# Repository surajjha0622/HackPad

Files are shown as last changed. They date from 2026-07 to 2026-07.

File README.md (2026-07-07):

# HackPad

A compact 6-key programmable macropad built using the **Seeed Studio XIAO RP2040**.

HackPad started as a project to learn the complete hardware design workflow—from schematic capture and PCB design to enclosure design and firmware development. Instead of using an existing macropad, I wanted to build one from scratch and understand every part of the process.

The project combines mechanical switches, a rotary encoder, and a small OLED display into a compact device that can be customized for productivity, media control, programming shortcuts, CAD software, or everyday workflows.

---

## Features

- 6 Mechanical Keys
- Rotary Encoder with Push Button
- 0.91" SSD1306 OLED Display
- USB Type-C Connectivity
- Powered by Seeed Studio XIAO RP2040
- Custom PCB designed in KiCad
- 3D Printed Enclosure
- QMK Firmware 

---

## PCB

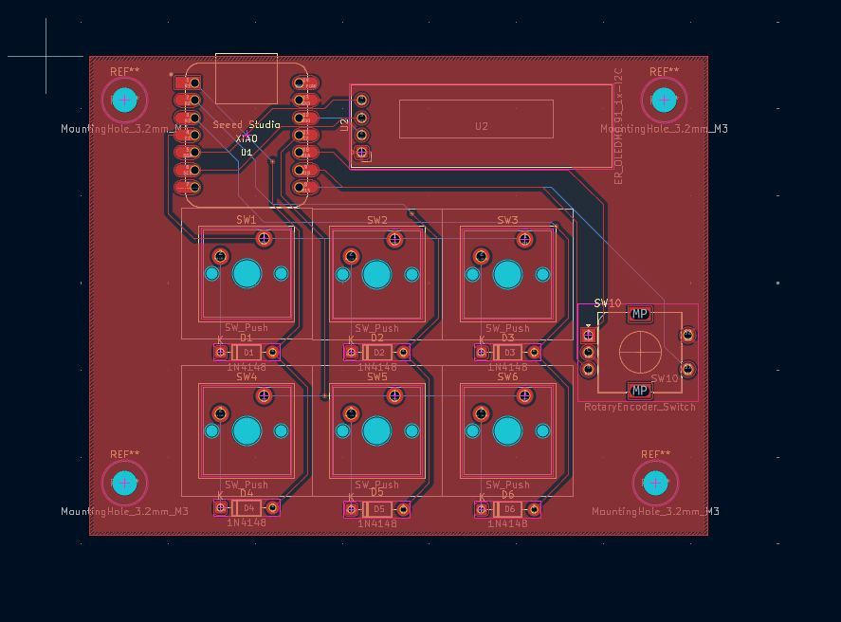
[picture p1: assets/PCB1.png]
PCB


---

## Schematic

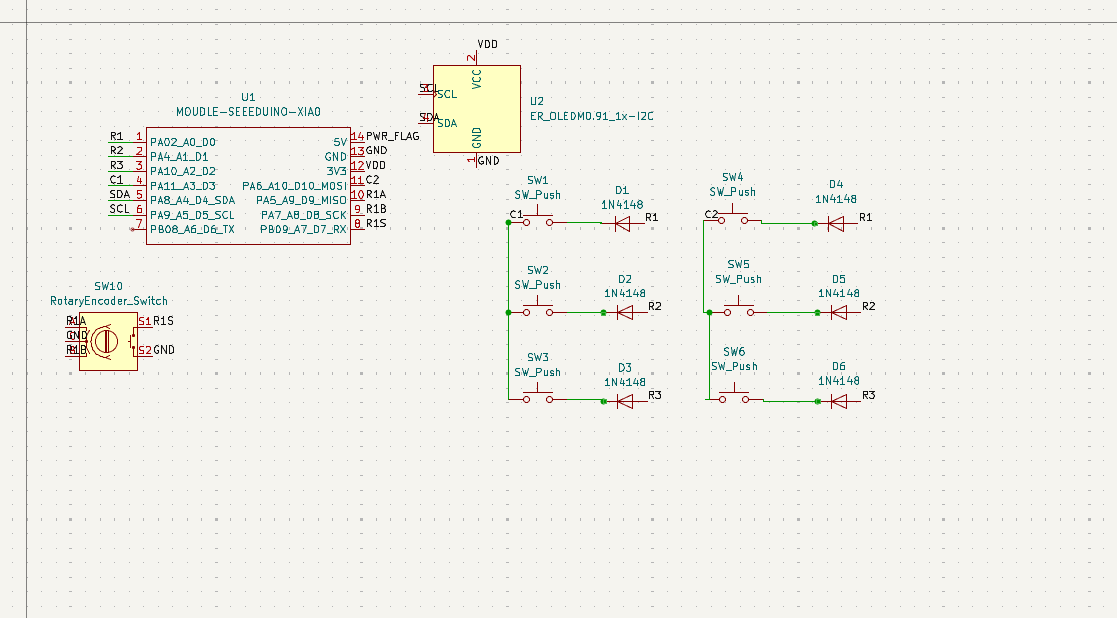
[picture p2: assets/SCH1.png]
SCHEMATICS


---

## 3D PCB Render

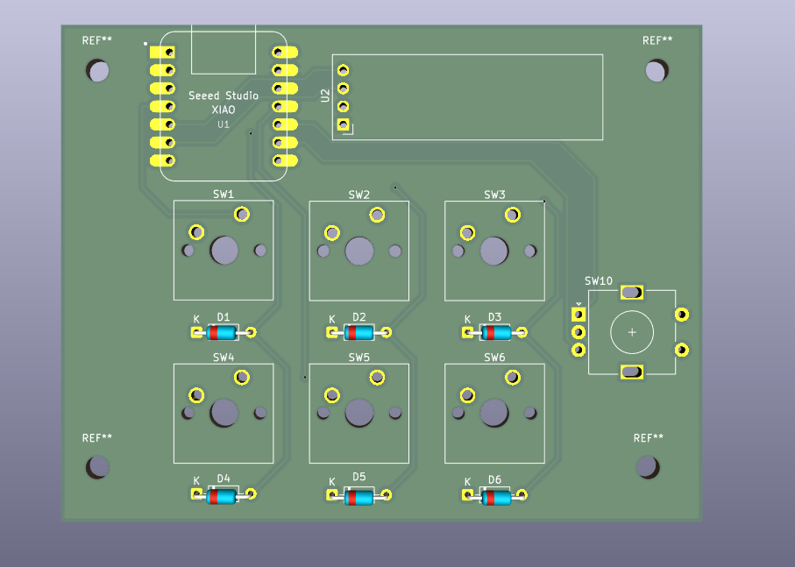
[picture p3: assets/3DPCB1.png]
3D PCB


---

## Enclosure Design

| Front | Edge |
|:---:|:----:|
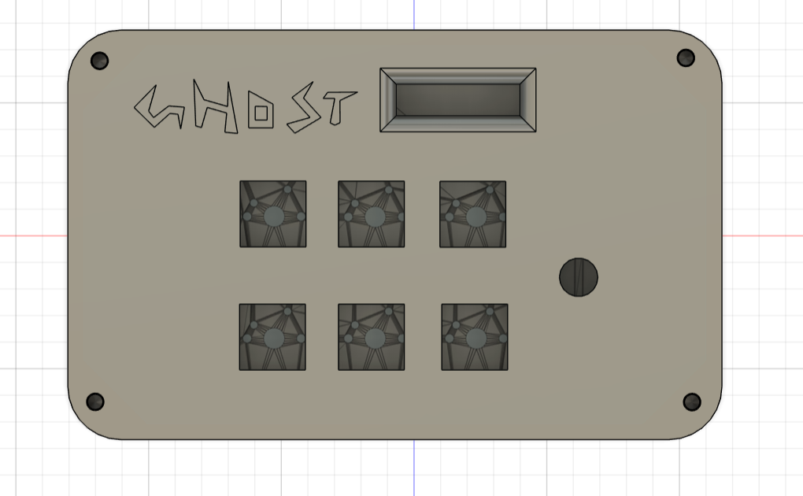
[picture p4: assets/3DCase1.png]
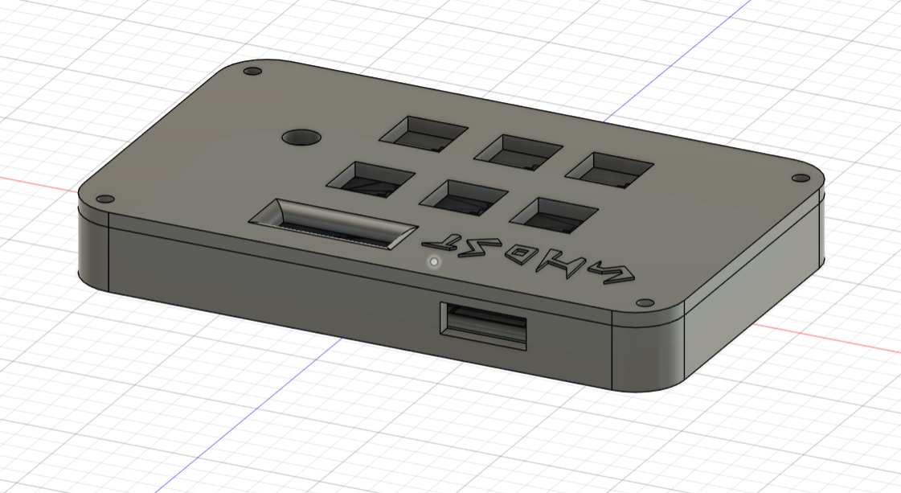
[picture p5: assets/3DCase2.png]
|  |  |

<p align="center">
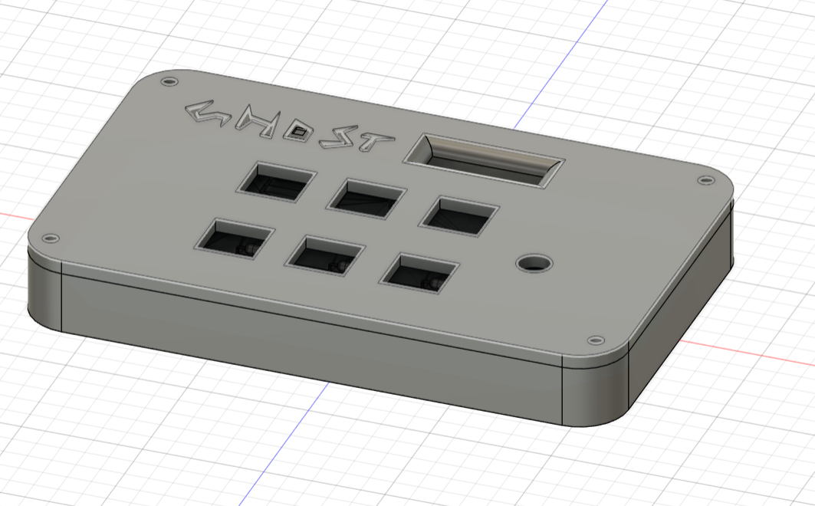
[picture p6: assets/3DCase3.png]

</p>

---

## Tech Stack

- KiCad 9
- Seeed Studio XIAO RP2040
- QMK Firmware *(In Progress)*
- 3D Printing
- Git & GitHub

---

## Current Status

- ✅ Schematic Complete
- ✅ PCB Designed
- ✅ 3D PCB Verified
- ✅ Enclosure Designed
- ✅ Gerber Files Generated
- 🔄 Firmware Development
- ⏳ PCB Manufacturing
- ⏳ Assembly & Testing

---

## What I Learned

This project helped me gain hands-on experience with:

- PCB Design
- Schematic Design
- Component Selection
- PCB Routing
- 3D Enclosure Design
- Hardware Documentation
- GitHub Project Organization

---

## 🤝 Feedback

This project is still evolving, and I'd love to hear suggestions or ideas for improvements. If you spot something that could be done better, feel free to open an issue or reach out!

Thanks for checking out HackPad! 🚀

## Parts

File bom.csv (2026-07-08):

Item | Quantity | Estimated Cost (USD)
Seeed Studio XIAO RP2040 | 1 | Included in Kit
MX-Style Mechanical Switches | 6 | Included in Kit
White DSA Keycaps | 6 | Included in Kit
1N4148 Through-Hole Diodes | 6 | Included in Kit
EC11 Rotary Encoder | 1 | Included in Kit
0.91" SSD1306 OLED Display | 1 | Included in Kit
Custom PCB | 1 | $10.00
3D Printed Enclosure | 1 | $10.00
M3 Heatset Inserts | 6 | Included in Kit
M3×16mm Screws | 6 | Included in Kit
Solder Wire | 1 | $2.00
Flux | 1 | $3.00
Soldering Iron | 1 | $15.00

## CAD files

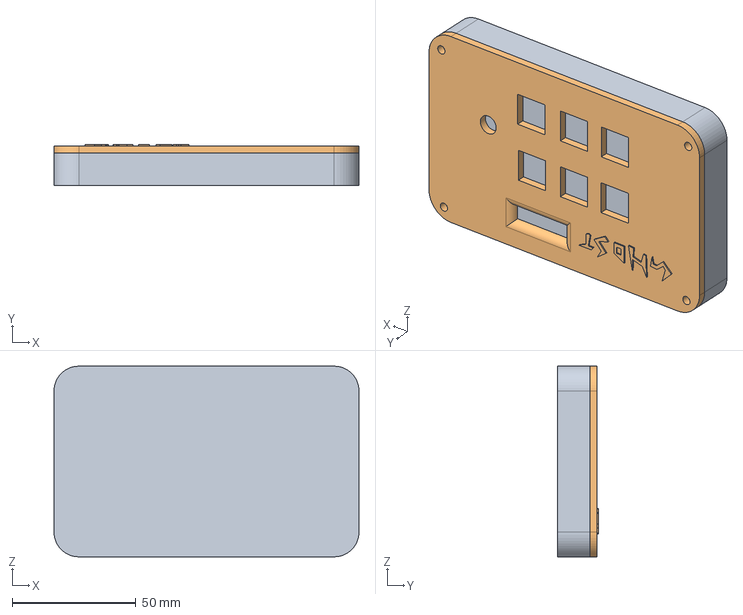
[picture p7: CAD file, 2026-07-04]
hardware/CAD/HackPad_Case_v1.step
123.2 x 16.5 x 77.0 mm

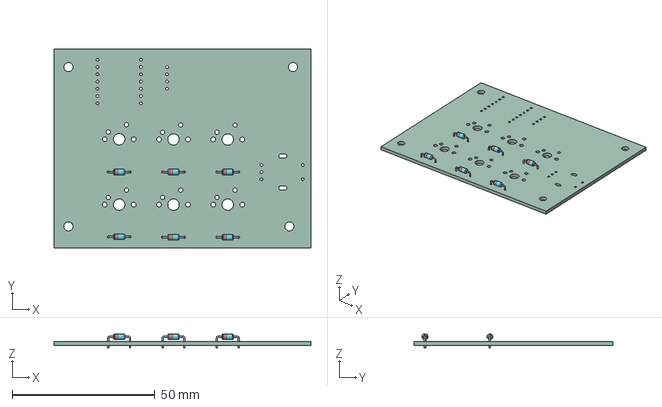
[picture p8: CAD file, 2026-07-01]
hardware/CAD/.step
90.2 x 69.9 x 5.01 mm
D_DO-35_SOD27_P7.62mm_Horizontal x 6
MicroPad_PCB

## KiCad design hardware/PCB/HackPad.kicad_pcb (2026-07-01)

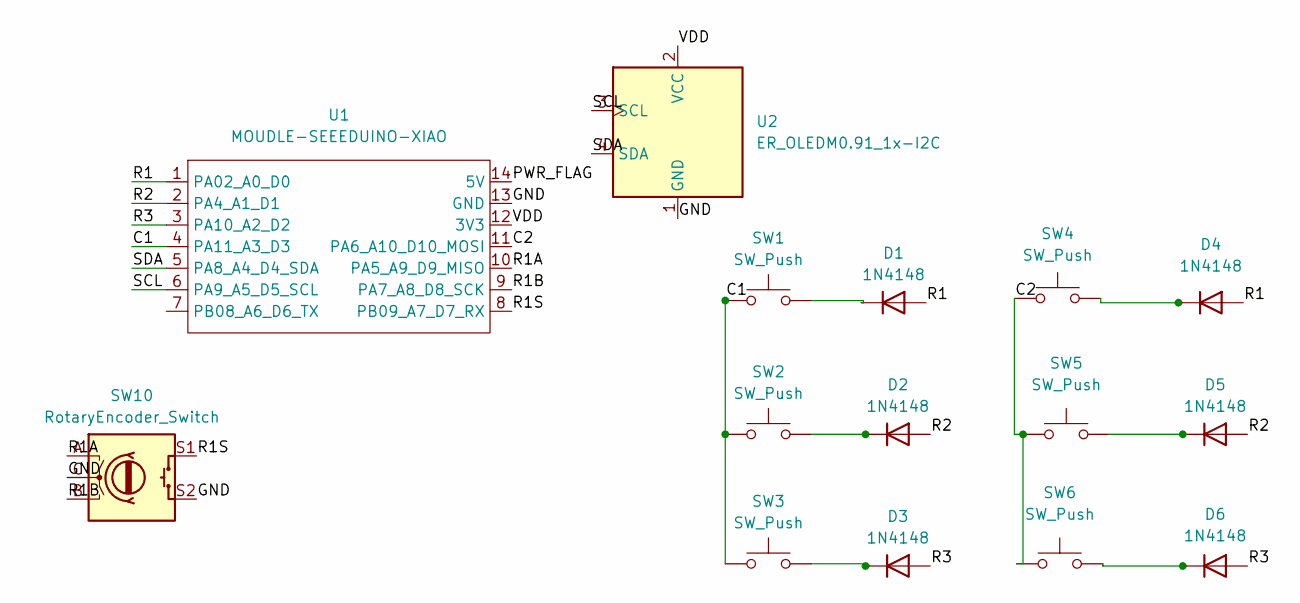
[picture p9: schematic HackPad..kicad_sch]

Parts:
D1, D2, D3, D4, D5, D6: 1N4148; D_DO-35_SOD27_P7.62mm_Horizontal
SW1, SW2, SW3, SW4, SW5, SW6: SW_Push; SW_Cherry_MX_1.00u_PCB
SW10: RotaryEncoder_Switch; RotaryEncoder_Alps_EC11E-Switch_Vertical_H20mm
U1: MOUDLE-SEEEDUINO-XIAO; XIAO-Generic-Hybrid-14P-2.54-21X17.8MM
U2: ER_OLEDM0.91_1x-I2C

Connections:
/C1: SW1.1, SW2.1, SW3.1, U1.4 (PA11_A3_D3)
/C2: SW4.1, SW5.1, SW6.1, U1.11 (PA6_A10_D10_MOSI)
/GND: SW10.C, SW10.S2, U1.13 (GND), U2.1 (GND)
/PWR_FLAG: U1.14 (5V)
/R1: D1.2 (A), D4.2 (A), U1.1 (PA02_A0_D0)
/R1A: SW10.A, U1.10 (PA5_A9_D9_MISO)
/R1B: SW10.B, U1.9 (PA7_A8_D8_SCK)
/R1S: SW10.S1, U1.8 (PB09_A7_D7_RX)
/R2: D2.2 (A), D5.2 (A), U1.2 (PA4_A1_D1)
/R3: D3.2 (A), D6.2 (A), U1.3 (PA10_A2_D2)
/SCL: U1.6 (PA9_A5_D5_SCL), U2.3 (SCL)
/SDA: U1.5 (PA8_A4_D4_SDA), U2.4 (SDA)
/VDD: U1.12 (3V3), U2.2 (VCC)
unnamed: D1.1 (K), SW1.2
unnamed: D2.1 (K), SW2.2
unnamed: D3.1 (K), SW3.2
unnamed: D4.1 (K), SW4.2
unnamed: D5.1 (K), SW5.2
unnamed: D6.1 (K), SW6.2

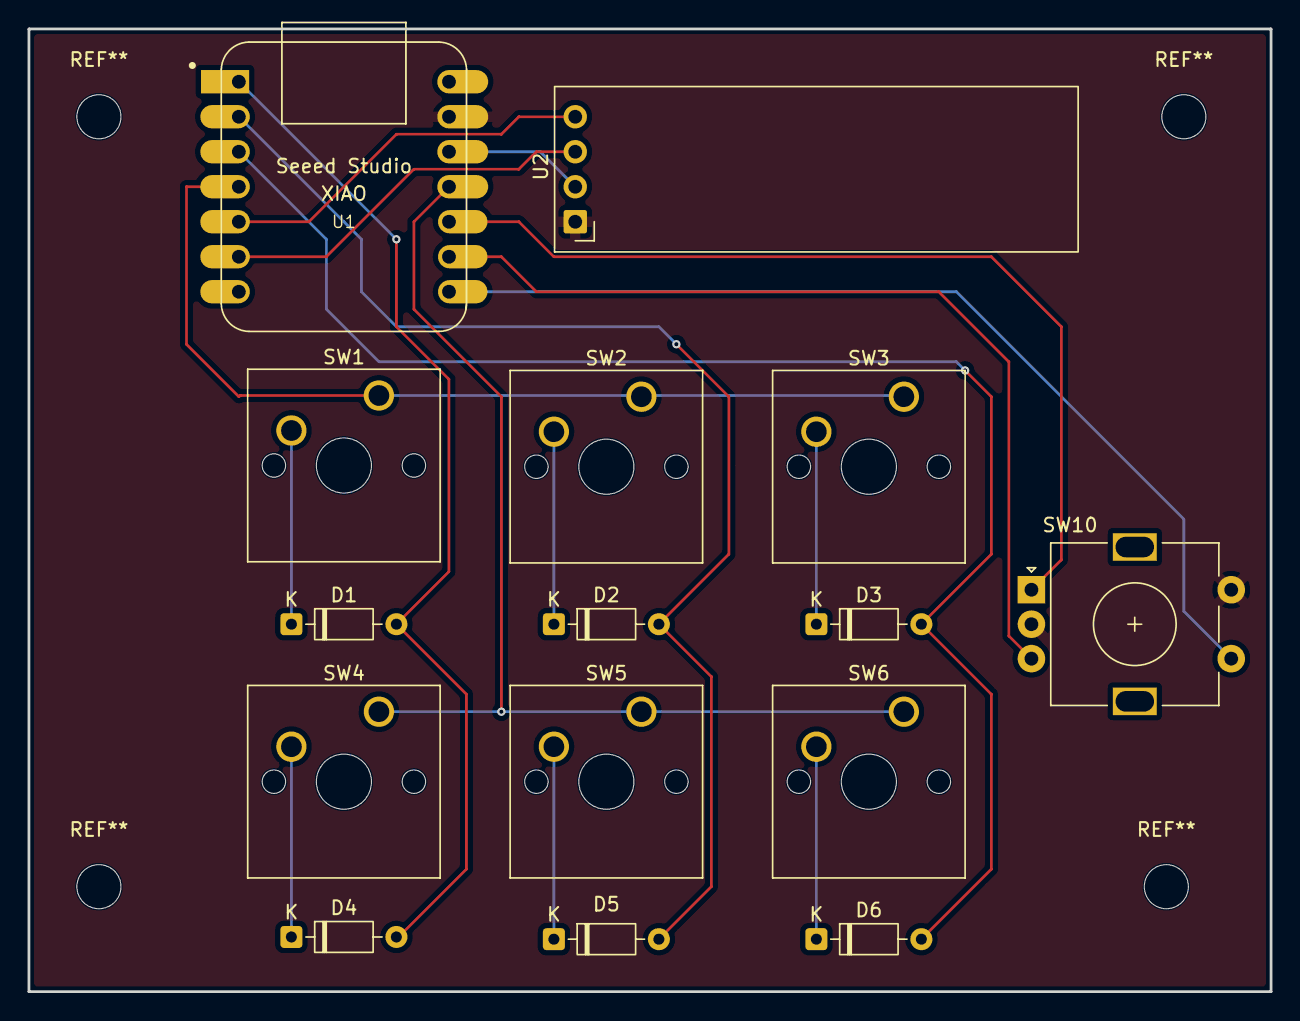
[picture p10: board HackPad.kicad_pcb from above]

Board: 2 copper layers, 90.2 x 69.9 mm, 15 parts (0 on the bottom side), 18 nets.

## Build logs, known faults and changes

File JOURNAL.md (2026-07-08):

---
title: "HackPad Journal"
author: "SURAJ K. JHA"
description: "Development journal for my custom HackPad."
created_at: "2026-06-12"
---

# June 12: Learning KiCad for PCB Designing

Started working on the PCB design for my custom HackPad.

Learning KiCad was harder than I expected, but the guides made the process much easier to follow. One thing that confused me was the guide mentioning a switch footprint from the care package. I couldn't find the exact footprint, so I used a similar switch footprint instead.

By the end of today's session I had almost completed the schematic and reached the PCB routing stage. I decided to stop there and continue later with a fresh mind instead of rushing through the routing.

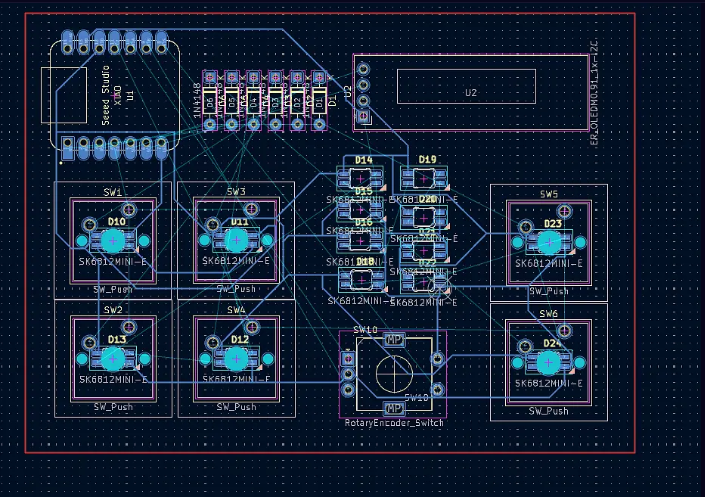
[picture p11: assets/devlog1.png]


**Total time spent: 4 hours**

# June 26: Progress on PCB Design

Finally finished the PCB!

This was much more frustrating than I expected. Three different times I completed almost the entire PCB, ran the DRC, and KiCad froze before closing without saving my work.

After rebuilding the design multiple times, I finally remembered to save before running DRC. Thankfully everything went smoothly after that and I completed the PCB.

Lesson learned: **Save before every DRC check.**

Schematic Design

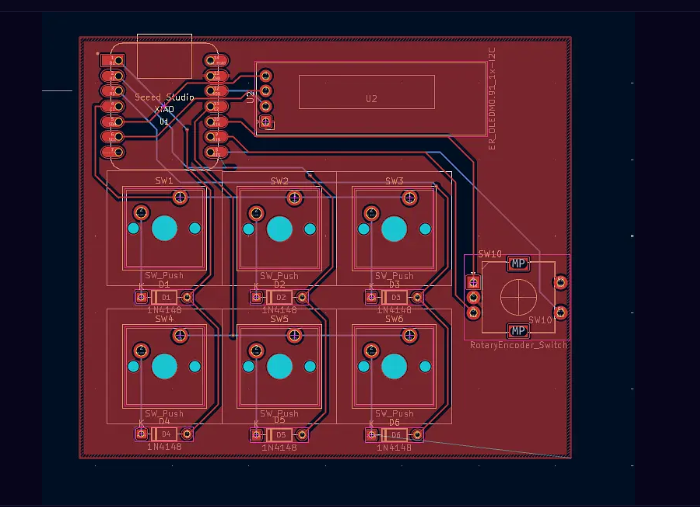
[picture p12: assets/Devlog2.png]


PCB Model

**Total time spent: 1 hours 50 minutes**

# June 27: Started Designing Enclosure

Started designing the enclosure for the HackPad.

Finding the correct dimensions for the switches, display, and other components took much longer than expected. Every enclosure project teaches me how much I still have to learn about CAD design.

One thing I realized is that I waste a Started Designing Enclosurlot of time stopping to measure parts while designing. Next time I'll note down every important dimension beforehand so I can stay focused throughout the design session.

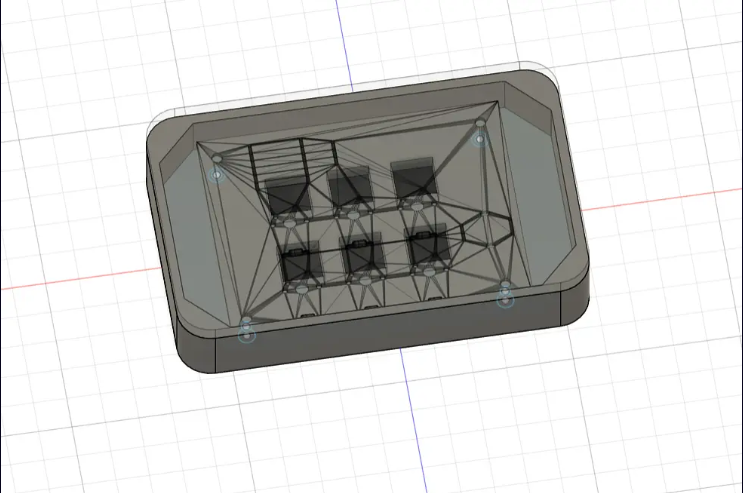
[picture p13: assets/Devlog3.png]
Enclosure Designing


**Total time spent: 1 hours 30 minutes**

# June 29: Done with Enclosure Design

Today I started enclosure design again and took reference designs and cad models help from grabcad and the help fom resources and guides of stardance.

Enclosure Design
Enclosure Design
Enclosure Design

**Total time spent: 4 hours**

# July 7: Update Repository with images files and journal 
 
Finally updated the repository with extra details in README.md .
Added Journals and did entry from Past devlogs from stardance.
Added images of designs.
**Total time spent: 2 hours**

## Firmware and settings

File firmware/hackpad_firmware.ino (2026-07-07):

// HackPad firmware for Seeed Studio XIAO RP2040

#include <Keyboard.h>
#include <Wire.h>
#include <Adafruit_GFX.h>
#include <Adafruit_SSD1306.h>
#include <Adafruit_NeoPixel.h>

// ---------------- pin map ----------------
constexpr uint8_t ROW_PINS[3] = { D0, D1, D2 };
constexpr uint8_t COL_PINS[2] = { D3, D10 };
constexpr uint8_t ENC_A_PIN   = D9;
constexpr uint8_t ENC_B_PIN   = D8;
constexpr uint8_t ENC_SW_PIN  = D7;

// Onboard XIAO RP2040 NeoPixel (not on the HackPad schematic - built into the module)
constexpr uint8_t NEOPIXEL_POWER_PIN = 11;
constexpr uint8_t NEOPIXEL_DATA_PIN  = 12;
Adafruit_NeoPixel statusLED(1, NEOPIXEL_DATA_PIN, NEO_GRB + NEO_KHZ800);

// ---------------- OLED ----------------
constexpr uint8_t SCREEN_W = 128;
constexpr uint8_t SCREEN_H = 32;
constexpr uint8_t OLED_ADDR = 0x3C;   // try 0x3D if init fails
Adafruit_SSD1306 display(SCREEN_W, SCREEN_H, &Wire, -1);

// ---------------- keymap: edit here to remap ----------------
// One HID keycode per switch. `modifier` is a single optional modifier key
// (KEY_LEFT_CTRL / KEY_LEFT_SHIFT / KEY_LEFT_ALT / KEY_LEFT_GUI), or 0.
struct KeyAction {
  uint8_t modifier;
  uint8_t key;
  const char* label;
};

KeyAction keymap[3][2] = {
  { {0,             'z',        "Undo"},  {0,             'y',       "Redo"}  },
  { {0,             'c',        "Copy"},  {0,             'v',       "Paste"} },
  { {KEY_LEFT_CTRL, 's',        "Save"},  {0,             KEY_RETURN,"Enter"} },
};

// ---------------- debounce state ----------------
constexpr uint16_t DEBOUNCE_MS = 15;
bool keyRaw[3][2]         = {false};
bool keyStable[3][2]      = {false};
uint32_t keyLastChange[3][2] = {0};

// ---------------- encoder state ----------------
uint8_t encPrevState = 0;
bool encSwRaw = false, encSwStable = false;
uint32_t encSwLastChange = 0;

const char* lastAction = "Ready";

void setup() {
  for (uint8_t r = 0; r < 3; r++) pinMode(ROW_PINS[r], INPUT);   // idle = Hi-Z
  for (uint8_t c = 0; c < 2; c++) pinMode(COL_PINS[c], INPUT_PULLUP);

  pinMode(ENC_A_PIN, INPUT_PULLUP);
  pinMode(ENC_B_PIN, INPUT_PULLUP);
  pinMode(ENC_SW_PIN, INPUT_PULLUP);
  encPrevState = (digitalRead(ENC_A_PIN) << 1) | digitalRead(ENC_B_PIN);

  Keyboard.begin();

  pinMode(NEOPIXEL_POWER_PIN, OUTPUT);
  digitalWrite(NEOPIXEL_POWER_PIN, HIGH);   // XIAO RP2040 needs this to power the LED
  statusLED.begin();
  statusLED.setBrightness(40);
  setLED(0, 20, 20);   // idle color

  Wire.begin();
  if (display.begin(SSD1306_SWITCHCAPVCC, OLED_ADDR)) {
    display.setTextColor(SSD1306_WHITE);
    drawScreen();
  }
}

void loop() {
  scanMatrix();
  pollEncoder();
  pollEncoderSwitch();
}

// ---------------- matrix scan ----------------
void scanMatrix() {
  for (uint8_t r = 0; r < 3; r++) {
    pinMode(ROW_PINS[r], OUTPUT);
    digitalWrite(ROW_PINS[r], LOW);
    delayMicroseconds(5);

    for (uint8_t c = 0; c < 2; c++) {
      bool pressed = (digitalRead(COL_PINS[c]) == LOW);
      if (pressed != keyRaw[r][c]) {
        keyRaw[r][c] = pressed;
        keyLastChange[r][c] = millis();
      }
      if (millis() - keyLastChange[r][c] > DEBOUNCE_MS &&
          keyRaw[r][c] != keyStable[r][c]) {
        keyStable[r][c] = keyRaw[r][c];
        handleKey(r, c, keyStable[r][c]);
      }
    }

    pinMode(ROW_PINS[r], INPUT);   // release row before scanning the next
  }
}

void handleKey(uint8_t r, uint8_t c, bool pressed) {
  KeyAction &a = keymap[r][c];
  if (pressed) {
    if (a.modifier) Keyboard.press(a.modifier);
    Keyboard.press(a.key);
    lastAction = a.label;
    setLED(0, 255, 60);
    drawScreen();
  } else {
    Keyboard.release(a.key);
    if (a.modifier) Keyboard.release(a.modifier);
    setLED(0, 20, 20);
  }
}

// ---------------- rotary encoder (quadrature) ----------------
void pollEncoder() {
  uint8_t state = (digitalRead(ENC_A_PIN) << 1) | digitalRead(ENC_B_PIN);
  if (state != encPrevState) {
    static const int8_t table[16] = {
       0, -1,  1,  0,
       1,  0,  0, -1,
      -1,  0,  0,  1,
       0,  1, -1,  0
    };
    int8_t dir = table[(encPrevState << 2) | state];
    encPrevState = state;
    if (dir > 0) {
      Keyboard.write(KEY_UP_ARROW);     // swap for media keys if you prefer
      lastAction = "Scroll +";
      drawScreen();
    } else if (dir < 0) {
      Keyboard.write(KEY_DOWN_ARROW);
      lastAction = "Scroll -";
      drawScreen();
    }
  }
}

void pollEncoderSwitch() {
  bool pressed = (digitalRead(ENC_SW_PIN) == LOW);
  if (pressed != encSwRaw) {
    encSwRaw = pressed;
    encSwLastChange = millis();
  }
  if (millis() - encSwLastChange > DEBOUNCE_MS && pressed != encSwStable) {
    encSwStable = pressed;
    if (pressed) {
      Keyboard.press(KEY_LEFT_GUI);   // default: launcher/search key tap
      lastAction = "Knob press";
      setLED(60, 0, 255);
      drawScreen();
    } else {
      Keyboard.release(KEY_LEFT_GUI);
      setLED(0, 20, 20);
    }
  }
}

// ---------------- display / LED helpers ----------------
void drawScreen() {
  display.clearDisplay();
  display.setTextSize(1);
  display.setCursor(0, 0);
  display.println("HackPad");
  display.setTextSize(2);
  display.setCursor(0, 14);
  display.println(lastAction);
  display.display();
}

void setLED(uint8_t r, uint8_t g, uint8_t b) {
  statusLED.setPixelColor(0, statusLED.Color(r, g, b));
  statusLED.show();
}

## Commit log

2026-07-01 add PCB files
    [HackPad.kicad_pcb]
2026-07-01 add PCB 3D files
    [.step]
2026-07-01 add HackPad case step file
    [HackPad Case.step]
2026-07-04 add enclosure png file
2026-07-04 add pcb png file
2026-07-04 update Enclosure step file
    [HackPad Case.step, HackPad_Case_v1.step]
2026-07-07 remove redundant descriptions from PCB and schematic sections in README
2026-07-07 add JOURNAL.md to track project progress and notes
2026-07-08 add bill of materials (BOM) for HackPad components
    [bom.csv]
